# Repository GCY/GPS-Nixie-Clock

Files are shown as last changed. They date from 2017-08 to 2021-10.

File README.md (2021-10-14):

# GPS-Nixie-Clock

This is GPS Nixie clock,include IN12B, IN14, IN16, and IN2 version.</br>

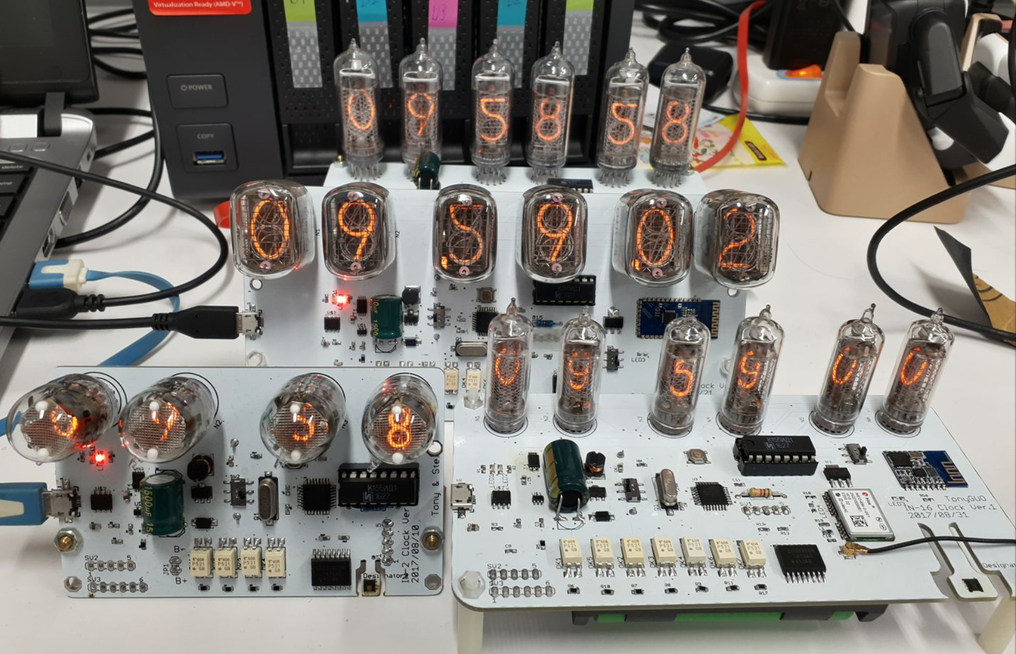
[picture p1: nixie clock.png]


## Firmware
### Parameter

__SERIAL__ : output info to serial port.</br>
DOT : use nixie tube dot.</br>
__GPS__ : time sync with Neo-6M - u-blox chip, this function only for IN14 IN16 version, and time sync separator is GPGGA[7] = {'$','G','P','G','G','A',','};</br>
<pre><code>
#define __SERIAL__ 1
#define DOT 1
#define __GPS__ 1
</code></pre>

gps_update : gps sync period, unit is ms, 300000ms = 5min.</br> 
<pre><code>
const unsigned long gps_update = 300000;
</code></pre>

Type select, IN_14 == IN_16.</br> 
<pre><code>
enum{
  IN_12B = 100,
  IN_14,
  IN_2
};
</code></pre>

<pre><code>
const bool sync_time = false; // sync time with Arduino IDE
const bool temperature_calibration = false; // offset
const bool dew_point = true;  // calculate dew point
</code></pre>
### Command

case '1' : clock mode
</br>
case '2' : temperature mode
</br>
case '3' : humidity mode
</br>
case '4' : flash mode
</br>
case '5' : counter mode
</br>
case '6' : '1' + '2' + '3'
</br>
case 's' | 'S' : set time
</br></br>

## Android time sync tool
Android App modified BlueTerm project. </br>

## PC Software - wxNixieClock
</br>
wxNixieClock is time sync tool for Nixie Clock project.(Only MAC-OS-X)</br>

### Build

g++ -o2 -o wxnixieclock.app wxnixieclock.cpp serialport.cpp connectargsdlg.cpp \`wx-config --cxxflags --libs\` -m64</br>
</br>
</br>

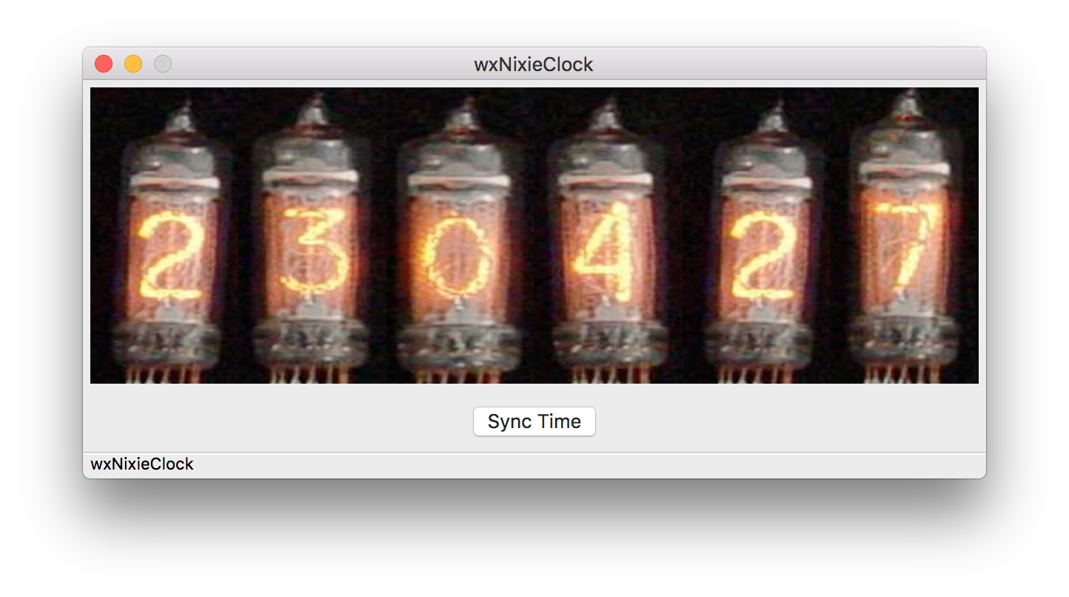
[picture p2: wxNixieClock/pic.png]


</br>
</br>

Audi R8 (https://youtu.be/tJzohsqhTxs)

### Use
</br>
1. Pair BT of MAC and Nixie Clock.</br>
2. Open wxNixieClock to select tools -> Connect Device -> cu.BT device driver</br>
3. Click SyncTime button</br>
4. Done!</br>
</br>

### Dependency

</br>
Install wxWidgets dependency in terminal</br>
</br>
1. user$ /usr/bin/ruby -e "$(curl -fsSL https://raw.githubusercontent.com/Homebrew/install/master/install)" </br>
2. brew install wxwidgets </br>

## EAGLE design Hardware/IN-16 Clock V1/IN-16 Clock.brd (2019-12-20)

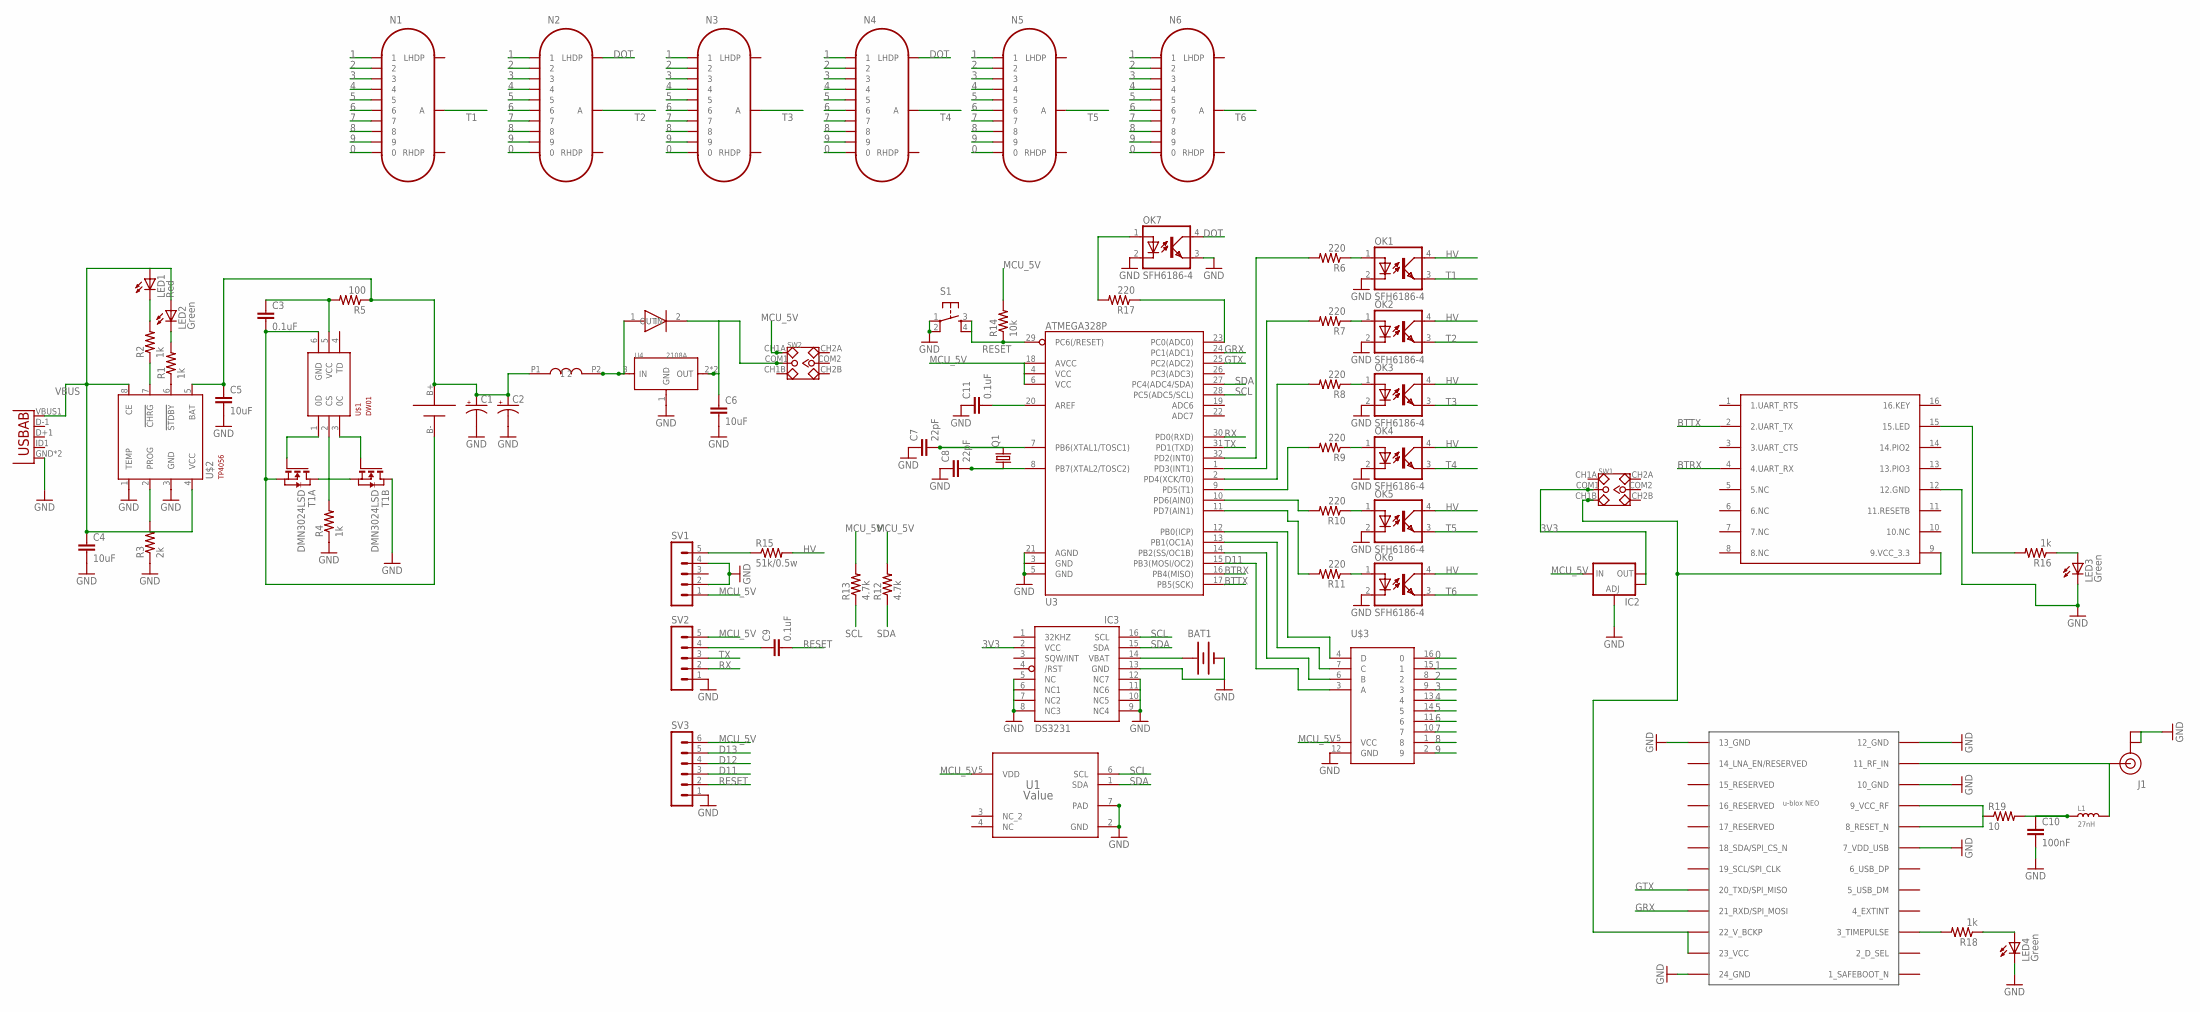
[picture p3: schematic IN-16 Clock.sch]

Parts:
BAT1: BATTERY20PTH; BATTCOM_20MM_PTH
C1, C2: CAP_POLF80; NIPPON_F80
C3, C9, C11: 0.1uF; 0603-CAP
C4, C5, C6: 10uF; 0603-CAP
C7, C8: 22pF; 0603-CAP
C10: 100nF; 0402-CAP
IC2: V_REG_LM1117SOT223; SOT223
IC3: DS3231/SO; SO16W
J1: U.FL
L1: 27nH; L0603
LED1: Red; CHIP-LED0805
LED2, LED3, LED4: Green; CHIP-LED0805
N1, N2, N3, N4, N5, N6: IN-16
OK1, OK2, OK3, OK4, OK5, OK6, OK7: SFH6186-4; SMD4-7
Q1: CRYSTALSM49; SM49
R1, R2, R4, R16, R18: 1k; 0603-RES
R3: 2k; 0603-RES
R5: 100; 0603-RES
R6, R7, R8, R9, R10, R11, R17: 220; 0603-RES
R12, R13: 4.7k; 0603-RES
R14: 10k; 0603-RES
R15: 51k/0.5w; 0207/12
R19: 10; 0603-RES
S1: TAC_SWITCHSMD; TACTILE_SWITCH_SMD
SV1, SV2: MA05-1
SV3: MA06-1
SW1, SW2: SMD-TOGGLE-SWITCH-2CH(2X3P-7X3.5MM); SW6-2.54-SMD-7.0X3.5X1.5MM
T1: DMN3024LSD; TSSOP-8
U1: Value; DMB0006A
U2: USB""; USB-MICRO-SMD
U3: ATMEGA328P; TQFP32-08
U4: 2108A; SOT-89
U$1: DW01; SOT23-6
U$2: TP4056; SOT23-8
U$3: K155ID1; DIL16-KIT
U$5: 22uH; CD54
U$6: SMA-SS34
U$7: 18650SMD
U$8: NEO-M8
U$9: HM-13

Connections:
0: N1.0, N2.0, N3.0, N4.0, N5.0, N6.0, U$3.16 (0)
1: N1.1, N2.1, N3.1, N4.1, N5.1, N6.1, U$3.15 (1)
2: N1.2, N2.2, N3.2, N4.2, N5.2, N6.2, U$3.8 (2)
3: N1.3, N2.3, N3.3, N4.3, N5.3, N6.3, U$3.9 (3)
3V3: IC2.2 (OUT), IC2.4 (OUT), IC3.2 (VCC), SW1.COM1
4: N1.4, N2.4, N3.4, N4.4, N5.4, N6.4, U$3.13 (4)
5: N1.5, N2.5, N3.5, N4.5, N5.5, N6.5, U$3.14 (5)
6: N1.6, N2.6, N3.6, N4.6, N5.6, N6.6, U$3.11 (6)
7: N1.7, N2.7, N3.7, N4.7, N5.7, N6.7, U$3.10 (7)
8: N1.8, N2.8, N3.8, N4.8, N5.8, N6.8, U$3.1 (8)
9: N1.9, N2.9, N3.9, N4.9, N5.9, N6.9, U$3.2 (9)
BTRX: U3.16 (PB4(MISO)), U$9.4 (4.UART_RX)
BTTX: U3.17 (PB5(SCK)), U$9.2 (2.UART_TX)
D11: SV3.3, U3.15 (PB3(MOSI/OC2)), U$3.3 (A)
D12: SV3.4
D13: SV3.5
DOT: N2.LHDP, N4.LHDP, OK7.4 (COL)
GND: BAT1.2 (-), C1.-, C2.-, C4.2, C5.2, C6.2, C7.1, C8.1, C10.2, C11.1, IC2.1 (ADJ), IC3.5 (NC), IC3.6 (NC1), IC3.7 (NC2), IC3.8 (NC3), IC3.9 (NC4), IC3.10 (NC5), IC3.11 (NC6), IC3.12 (NC7), IC3.13 (GND), J1.P$1 (GND), J1.P$2 (GND), LED3.C, LED4.C, OK1.2 (C), OK2.2 (C), OK3.2 (C), OK4.2 (C), OK5.2 (C), OK6.2 (C), OK7.2 (C), OK7.3 (EMIT), R3.1, R4.1, S1.1, S1.2, SV1.2, SV1.4, SV2.1, SV3.1, T1.8 (D), U1.2 (GND), U1.7 (PAD), U2.GND, U2.GND1 (GND), U3.3 (GND), U3.5 (GND), U3.21 (AGND), U4.1 (GND), U$2.1 (TEMP), U$2.3 (GND), U$3.12 (GND), U$8.7 (7_VDD_USB), U$8.10 (10_GND), U$8.12 (12_GND), U$8.13 (13_GND), U$8.24 (24_GND), U$9.12 (12.GND)
GRX: U3.24 (PC1(ADC1)), U$8.21 (21_RXD/SPI_MOSI)
GTX: U3.25 (PC2(ADC2)), U$8.20 (20_TXD/SPI_MISO)
HV: OK1.4 (COL), OK2.4 (COL), OK3.4 (COL), OK4.4 (COL), OK5.4 (COL), OK6.4 (COL), R15.2
MCU_5V: IC2.3 (IN), R12.2, R13.2, R14.2, SV1.1, SV2.5, SV3.6, SW2.CH1A, U1.5 (VDD), U3.4 (VCC), U3.6 (VCC), U3.18 (AVCC), U$3.5 (VCC)
unnamed: LED2.C, R1.2
unnamed: R1.1, U$2.6 (!STDBY)
unnamed: LED1.C, R2.2
unnamed: R2.1, U$2.7 (!CHRG)
unnamed: R3.2, U$2.2 (PROG)
unnamed: U4.3 (IN), U$5.P2 (2), U$6.1 (IN)
unnamed: C6.1, SW2.COM1, U4.2 (OUT), U4.4 (OUT), U$6.2 (OUT)
unnamed: T1.1 (D), T1.6 (S), T1.7 (S)
unnamed: T1.4 (G), U$1.1 (0D)
unnamed: T1.5 (G), U$1.3 (0C)
unnamed: R4.2, U$1.2 (CS)
unnamed: C3.2, T1.2 (S), T1.3 (S), U$1.6 (GND), U$7.B-
unnamed: C3.1, R5.2, U$1.5 (VCC)
unnamed: C1.+, C2.+, C5.1, R5.1, U$2.5 (BAT), U$5.P1 (1), U$7.B+
unnamed: C7.2, Q1.2, U3.7 (PB6(XTAL1/TOSC1))
unnamed: C8.2, Q1.1, U3.8 (PB7(XTAL2/TOSC2))
unnamed: BAT1.1 (+), IC3.14 (VBAT)
unnamed: C11.2, U3.20 (AREF)
unnamed: R15.1, SV1.5
unnamed: R18.2, U$8.3 (3_TIMEPULSE)
unnamed: LED4.A, R18.1
unnamed: OK1.1 (A), R6.1
unnamed: OK2.1 (A), R7.1
unnamed: OK3.1 (A), R8.1
unnamed: OK4.1 (A), R9.1
unnamed: OK5.1 (A), R10.1
unnamed: OK6.1 (A), R11.1
unnamed: R6.2, U3.32 (PD2(INT0))
unnamed: R7.2, U3.1 (PD3(INT1))
unnamed: R8.2, U3.2 (PD4(XCK/T0))
unnamed: R9.2, U3.9 (PD5(T1))
unnamed: R10.2, U3.10 (PD6(AIN0))
unnamed: R11.2, U3.11 (PD7(AIN1))
unnamed: U3.12 (PB0(ICP)), U$3.4 (D)
unnamed: U3.13 (PB1(OC1A)), U$3.7 (C)
unnamed: U3.14 (PB2(SS/OC1B)), U$3.6 (B)
unnamed: R17.1, U3.23 (PC0(ADC0))
unnamed: SW1.CH1B, U$8.22 (22_V_BCKP), U$8.23 (23_VCC), U$9.9 (9.VCC_3.3)
unnamed: OK7.1 (A), R17.2
unnamed: C9.1, SV2.4
unnamed: R16.2, U$9.15 (15.LED)
unnamed: LED3.A, R16.1
unnamed: C10.1, L1.1, R19.2
unnamed: R19.1, U$8.8 (8_RESET_N), U$8.9 (9_VCC_RF)
unnamed: J1.P$3 (SIGNAL), L1.2, U$8.11 (11_RF_IN)
RESET: C9.2, R14.1, S1.3, S1.4, SV3.2, U3.29 (PC6(/RESET))
RX: SV2.2, U3.30 (PD0(RXD))
SCL: IC3.16 (SCL), R13.1, U1.6 (SCL), U3.28 (PC5(ADC5/SCL))
SDA: IC3.15 (SDA), R12.1, U1.1 (SDA), U3.27 (PC4(ADC4/SDA))
T1: N1.A, OK1.3 (EMIT)
T2: N2.A, OK2.3 (EMIT)
T3: N3.A, OK3.3 (EMIT)
T4: N4.A, OK4.3 (EMIT)
T5: N5.A, OK5.3 (EMIT)
T6: N6.A, OK6.3 (EMIT)
TX: SV2.3, U3.31 (PD1(TXD))
VBUS: C4.1, LED1.A, LED2.A, U2.VBUS1 (VBUS), U$2.4 (VCC), U$2.8 (CE)

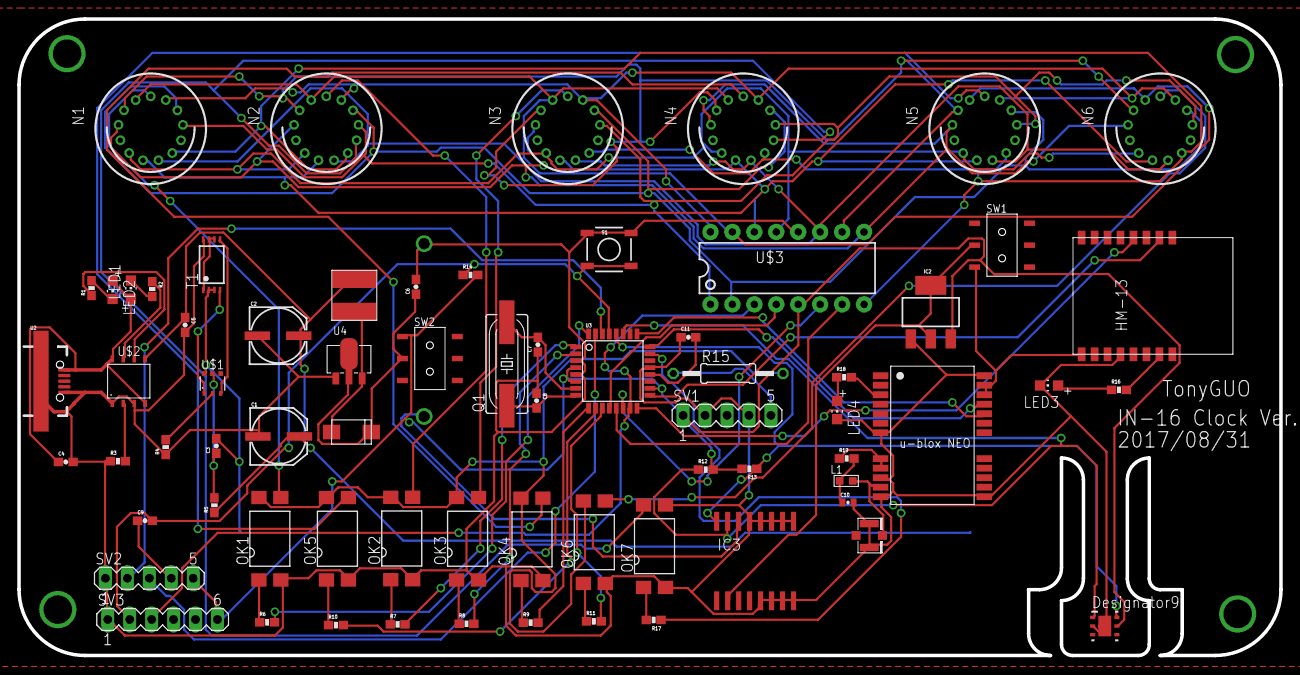
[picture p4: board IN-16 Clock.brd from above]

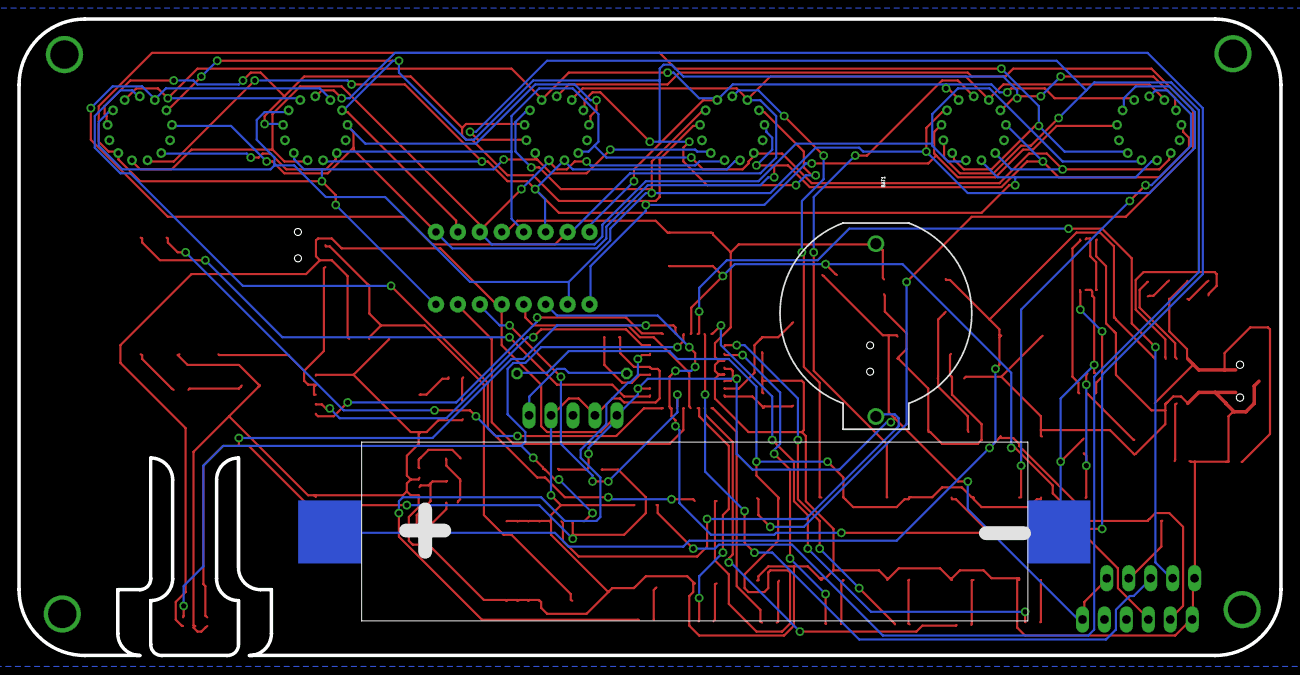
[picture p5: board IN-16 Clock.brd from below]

Board: 2 copper layers, 146.0 x 73.7 mm, 72 parts (2 on the bottom side), 77 nets.

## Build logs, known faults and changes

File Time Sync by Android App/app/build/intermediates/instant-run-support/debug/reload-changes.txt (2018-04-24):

CHANGED,/Users/gcy/Downloads/RoBoHoN connect TPR device/BlueTerm-master/app/build/intermediates/transforms/instantRun/debug/folders/4000/5/enhanced/es/pymasde/blueterm/BlueTerm$3$override.class
CHANGED,/Users/gcy/Downloads/RoBoHoN connect TPR device/BlueTerm-master/app/build/intermediates/transforms/instantRun/debug/folders/4000/5/enhanced/es/pymasde/blueterm/EmulatorView$1$override.class
CHANGED,/Users/gcy/Downloads/RoBoHoN connect TPR device/BlueTerm-master/app/build/intermediates/transforms/instantRun/debug/folders/4000/5/enhanced/es/pymasde/blueterm/BlueTerm$5$override.class
CHANGED,/Users/gcy/Downloads/RoBoHoN connect TPR device/BlueTerm-master/app/build/intermediates/transforms/instantRun/debug/folders/4000/5/enhanced/es/pymasde/blueterm/EmulatorView$2$override.class
CHANGED,/Users/gcy/Downloads/RoBoHoN connect TPR device/BlueTerm-master/app/build/intermediates/transforms/instantRun/debug/folders/4000/5/enhanced/es/pymasde/blueterm/TermKeyListener$override.class
CHANGED,/Users/gcy/Downloads/RoBoHoN connect TPR device/BlueTerm-master/app/build/intermediates/transforms/instantRun/debug/folders/4000/5/enhanced/es/pymasde/blueterm/TermKeyListener$ModifierKey$override.class
CHANGED,/Users/gcy/Downloads/RoBoHoN connect TPR device/BlueTerm-master/app/build/intermediates/transforms/instantRun/debug/folders/4000/5/enhanced/es/pymasde/blueterm/EmulatorView$override.class
CHANGED,/Users/gcy/Downloads/RoBoHoN connect TPR device/BlueTerm-master/app/build/intermediates/transforms/instantRun/debug/folders/4000/5/enhanced/com/android/tools/fd/runtime/AppPatchesLoaderImpl.class
CHANGED,/Users/gcy/Downloads/RoBoHoN connect TPR device/BlueTerm-master/app/build/intermediates/transforms/instantRun/debug/folders/4000/5/enhanced/es/pymasde/blueterm/TerminalEmulator$override.class
CHANGED,/Users/gcy/Downloads/RoBoHoN connect TPR device/BlueTerm-master/app/build/intermediates/transforms/instantRun/debug/folders/4000/5/enhanced/es/pymasde/blueterm/BaseTextRenderer$override.class
CHANGED,/Users/gcy/Downloads/RoBoHoN connect TPR device/BlueTerm-master/app/build/intermediates/transforms/instantRun/debug/folders/4000/5/enhanced/es/pymasde/blueterm/ByteQueue$override.class
CHANGED,/Users/gcy/Downloads/RoBoHoN connect TPR device/BlueTerm-master/app/build/intermediates/transforms/instantRun/debug/folders/4000/5/enhanced/es/pymasde/blueterm/BlueTerm$4$override.class
CHANGED,/Users/gcy/Downloads/RoBoHoN connect TPR device/BlueTerm-master/app/build/intermediates/transforms/instantRun/debug/folders/4000/5/enhanced/es/pymasde/blueterm/PaintRenderer$override.class
CHANGED,/Users/gcy/Downloads/RoBoHoN connect TPR device/BlueTerm-master/app/build/intermediates/transforms/instantRun/debug/folders/4000/5/enhanced/es/pymasde/blueterm/EmulatorView$3$override.class
CHANGED,/Users/gcy/Downloads/RoBoHoN connect TPR device/BlueTerm-master/app/build/intermediates/transforms/instantRun/debug/folders/4000/5/enhanced/es/pymasde/blueterm/BlueTerm$override.class
CHANGED,/Users/gcy/Downloads/RoBoHoN connect TPR device/BlueTerm-master/app/build/intermediates/transforms/instantRun/debug/folders/4000/5/enhanced/es/pymasde/blueterm/TranscriptScreen$override.class

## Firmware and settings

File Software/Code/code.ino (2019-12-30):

#define __SERIAL__ 1
#define DOT 1
#define __GPS__ 1

#ifdef DOT
bool dot = true;
#endif

#include <avr/wdt.h>
#include <Wire.h>
#include <EEPROM.h>

#ifdef __SERIAL__
#include <SoftwareSerial.h>
#endif

#include "RTClib.h"
#include "ClosedCube_HDC1080.h"

#ifdef __SERIAL__
SoftwareSerial serial(13, 12); // RX,TX
#endif

#ifdef __GPS__
#include <TinyGPS.h>

TinyGPS gps;
SoftwareSerial ss(16,15);

static const char GPGGA[7] = {'$','G','P','G','G','A',','};
int gps_sync_gmt_time_index = 0;
char gps_sync_gmt_time[6];

unsigned long gps_time = 0;
unsigned long timeout = 0;
boolean timeout_flag = false;
const unsigned long gps_update = 300000; /*86400000;*/
#endif

enum{
  IN_12B = 100,
  IN_14,
  IN_2
};

const int type = IN_14;

const bool sync_time = false;
const bool temperature_calibration = false;
const bool dew_point = true;

//RTC_DS1307 rtc;
RTC_DS3231 rtc;

ClosedCube_HDC1080 hdc1080;

unsigned long snt = 0;

int tubes[] = {2,3,4,5,6,7};
int K1551[] = {8,9,10,11};

float temperature = 0;
float humidity = 0;

int h = 0;
int m = 0;
int s = 0;  

unsigned long dot_last_time = 0;
unsigned long sn = 0;

unsigned short state = 0; 

const unsigned long s1 = 10000;
const unsigned long s2 = 12000;
const unsigned long s3 = 14000;
unsigned long sr = 0;

static char mode = '6';

float HDC1080DewPoint(float temperature,float humidity)
{
  return (243.12 * (log(humidity/100.0)+ ((17.62*temperature)/(243.12+temperature)))) / (17.62 - (log(humidity/100.0)+ ((17.62*temperature)/(243.12+temperature))));
}

void UpdateHDC1080Temperature()
{
  static int c = 0;
  static float temperature_t = 0;
  static const float ma = 1.0f;
  if(c < ma){
    temperature_t += hdc1080.readTemperature();
    ++c;
  }
  else if(c >= ma){
    temperature = temperature_t / ma;
    
    if(dew_point){
      temperature = HDC1080DewPoint(temperature,humidity);
    }
    
    if(temperature_calibration){
      //temperature -= 4.5f; // Offset
    }
    
    temperature_t = 0;
    c = 0; 
  }
}

void UpdateHDC1080Humidity()
{
  static int c = 0;
  static float humidity_t = 0;
  static const float ma = 1.0f;
  if(c < ma){
    humidity_t += hdc1080.readHumidity();
    ++c;
  }
  else if(c >= ma){
    humidity = humidity_t / ma;
    humidity_t = 0;
    c = 0;
  }
}

void BCD(int val)
{  
  if(val & 0x01){
    digitalWrite(K1551[3],HIGH);
  }
  else{
    digitalWrite(K1551[3],LOW);
  }
  if(val & 0x02){
    digitalWrite(K1551[2],HIGH);
  }
  else{
    digitalWrite(K1551[2],LOW);
  }  
  if(val & 0x04){
    digitalWrite(K1551[1],HIGH);
  }
  else{
    digitalWrite(K1551[1],LOW);
  }    
  if(val & 0x04){
    digitalWrite(K1551[1],HIGH);
  }
  else{
    digitalWrite(K1551[1],LOW);
  }    
  if(val & 0x08){
    digitalWrite(K1551[0],HIGH);
  }
  else{
    digitalWrite(K1551[0],LOW);
  }        
}

void DisplayTemperature()
{
  static const int dt1 = 200;   
  static const int dt2 = 800;   
   
  digitalWrite(tubes[5],LOW);
  delayMicroseconds(dt1);
  BCD(((int)temperature)/10);
  digitalWrite(tubes[2],HIGH);
  delayMicroseconds(dt2);
  digitalWrite(tubes[2],LOW);
  delayMicroseconds(dt1);
  BCD(((int)temperature)%10);
  digitalWrite(tubes[3],HIGH);
  delayMicroseconds(dt2);
  digitalWrite(tubes[3],LOW);
  delayMicroseconds(dt1);
  if(!(type == IN_2)){
    BCD( (int)( (temperature - ((int)temperature)) * 100) / 10);
    #ifdef DOT
    digitalWrite(A0,HIGH);
    #endif
    digitalWrite(tubes[4],HIGH);
    delayMicroseconds(dt2);
    #ifdef DOT
    digitalWrite(A0,LOW);
    #endif
    digitalWrite(tubes[4],LOW);
    delayMicroseconds(dt1);
    BCD( (int)( (temperature - ((int)temperature)) * 100) % 10);
    digitalWrite(tubes[5],HIGH);
    delayMicroseconds(dt2);   
    digitalWrite(tubes[5],LOW);  
  }
}

void DisplayHumidity()
{
  static const int dt1 = 200;    
  static const int dt2 = 800;
  digitalWrite(tubes[5],LOW);
  delayMicroseconds(dt1);
  BCD(((int)humidity)/10);
  digitalWrite(tubes[2],HIGH);
  delayMicroseconds(dt2);
  digitalWrite(tubes[2],LOW);
  delayMicroseconds(dt1);
  BCD(((int)humidity)%10);
  digitalWrite(tubes[3],HIGH);
  delayMicroseconds(dt2);
  digitalWrite(tubes[3],LOW);
  delayMicroseconds(dt1);
  if(!(type == IN_2)){
    BCD( (int)( (humidity - ((int)humidity)) * 100) / 10);
    #ifdef DOT
    digitalWrite(A0,HIGH);
    #endif
    digitalWrite(tubes[4],HIGH);
    delayMicroseconds(dt2);
    #ifdef DOT
    digitalWrite(A0,LOW);
    #endif
    digitalWrite(tubes[4],LOW);
    delayMicroseconds(dt1);
    BCD( (int)( (humidity - ((int)humidity)) * 100) % 10);
    digitalWrite(tubes[5],HIGH);
    delayMicroseconds(dt2);     
    digitalWrite(tubes[5],LOW);
  }
}

void DisplayTime()
{
  
  DateTime now = rtc.now();
  h = now.hour();
  m = now.minute();
  s = now.second();  

  static const int dt1 = 100;  
  static const int dt2 = 400;
  
  digitalWrite(tubes[5],LOW);
  delayMicroseconds(dt1);
  BCD(h/10);
  digitalWrite(tubes[0],HIGH);
  delayMicroseconds(dt2);
  digitalWrite(tubes[0],LOW);
  delayMicroseconds(dt1);
  BCD(h%10);  
  digitalWrite(tubes[1],HIGH);
  delayMicroseconds(dt2);
  digitalWrite(tubes[1],LOW);
  delayMicroseconds(dt1);
  BCD(m/10);
  #ifdef DOT
  if(dot){
    digitalWrite(A0,HIGH);
  }  
  #endif
  digitalWrite(tubes[2],HIGH);
  delayMicroseconds(dt2);
  #ifdef DOT
  if(dot){
    digitalWrite(A0,LOW);
  }  
  #endif
  digitalWrite(tubes[2],LOW);
  delayMicroseconds(dt1);
  BCD(m%10);
  digitalWrite(tubes[3],HIGH);
  delayMicroseconds(dt2);
  digitalWrite(tubes[3],LOW);
  delayMicroseconds(dt1);
  if(!(type == IN_2)){
    BCD(s/10);
    #ifdef DOT
    if(dot){
      digitalWrite(A0,HIGH);
    }  
    #endif
    digitalWrite(tubes[4],HIGH);
    delayMicroseconds(dt2);
    #ifdef DOT
    if(dot){
      digitalWrite(A0,LOW);
    }  
    #endif
    digitalWrite(tubes[4],LOW);
    delayMicroseconds(dt1);
    BCD(s%10);
    digitalWrite(tubes[5],HIGH);
    delayMicroseconds(dt2);   
    digitalWrite(tubes[5],LOW);
  }
}

void DisplayRandom()
{
  static const int dt1 = 500;  
  static const int dt2 = 10000;
  
  digitalWrite(tubes[5],LOW);
  delayMicroseconds(dt1);
  BCD(random(0,9));
  digitalWrite(tubes[0],HIGH);
  delayMicroseconds(dt2);
  digitalWrite(tubes[0],LOW);
  delayMicroseconds(dt1);
  BCD(random(0,9));
  digitalWrite(tubes[1],HIGH);
  delayMicroseconds(dt2);
  digitalWrite(tubes[1],LOW);
  delayMicroseconds(dt1);
  BCD(random(0,9));
  digitalWrite(tubes[2],HIGH);
  delayMicroseconds(dt2);
  digitalWrite(tubes[2],LOW);
  delayMicroseconds(dt1);
  BCD(random(0,9));
  digitalWrite(tubes[3],HIGH);
  delayMicroseconds(dt2);
  digitalWrite(tubes[3],LOW);
  delayMicroseconds(dt1);
  BCD(random(0,9));
  digitalWrite(tubes[4],HIGH);
  delayMicroseconds(dt2);
  digitalWrite(tubes[4],LOW);
  delayMicroseconds(dt1);
  BCD(random(0,9));
  digitalWrite(tubes[5],HIGH);
  delayMicroseconds(dt2);   
  digitalWrite(tubes[5],LOW);  
}

void DisplaySN()
{
  static const int dt1 = 200;  
  static const int dt2 = 800;
  
  digitalWrite(tubes[5],LOW);
  delayMicroseconds(dt1);
  BCD(sn);
  digitalWrite(tubes[0],HIGH);
  delayMicroseconds(dt2);
  digitalWrite(tubes[0],LOW);
  delayMicroseconds(dt1);
  BCD(sn);
  digitalWrite(tubes[1],HIGH);
  delayMicroseconds(dt2);
  digitalWrite(tubes[1],LOW);
  delayMicroseconds(dt1);
  BCD(sn);
  digitalWrite(tubes[2],HIGH);
  delayMicroseconds(dt2);
  digitalWrite(tubes[2],LOW);
  delayMicroseconds(dt1);
  BCD(sn);
  digitalWrite(tubes[3],HIGH);
  delayMicroseconds(dt2);
  digitalWrite(tubes[3],LOW);
  delayMicroseconds(dt1);
  BCD(sn);
  digitalWrite(tubes[4],HIGH);
  delayMicroseconds(dt2);
  digitalWrite(tubes[4],LOW);
  delayMicroseconds(dt1);
  BCD(sn);
  digitalWrite(tubes[5],HIGH);
  delayMicroseconds(dt2);   
  digitalWrite(tubes[5],LOW);
}

void setup() {

  wdt_enable (WDTO_1S);

  snt = millis();
  sr = millis();

  #ifdef __SERIAL__
  Serial.begin(9600);
  if(type == IN_12B){
    serial.begin(9600);
  }
  else if(type == IN_14){
    serial.begin(115200);
    #ifdef __GPS__
    //ss.begin(9600);
    gps_time = millis();
    #endif
  }
  #endif  
  
  Wire.begin();
  Wire.setClock(3400000);
  
  rtc.begin();
  if(sync_time){
    rtc.adjust(DateTime(F(__DATE__), F(__TIME__)));
  }
  
  hdc1080.begin(0x40);

  randomSeed(analogRead(A3));

  pinMode(A0,OUTPUT);
  
  for(int i = 0;i < (sizeof(tubes)/sizeof(tubes[0]));++i){
    pinMode(tubes[i],OUTPUT);
    digitalWrite(tubes[i],LOW);
  }
  for(int i = 0;i < (sizeof(K1551)/sizeof(K1551[0]));++i){
    pinMode(K1551[i],OUTPUT);
  } 

  UpdateHDC1080Temperature();
  UpdateHDC1080Humidity();

}

const static int set_time_length = 15;
char set_time[set_time_length];
char set_time_index = 0;

void loop() {
  #ifdef __SERIAL__

  while(Serial.available()) {
    char temp = Serial.read();
    
    if(temp >= '0' && temp <= '9'){
      mode = temp;
    }

    if(set_time_index < set_time_length){
      set_time[set_time_index++] = temp;
    }
    
    if(set_time_index == set_time_length){
      set_time_index = 0;
      if(set_time[0] == 's' || set_time[0] == 'S'){
        
        boolean set_time_flag = true;
        
        for(int i = 1;i < set_time_length;++i){
          if(set_time[i] >= '0' && set_time[i] <= '9'){
          }
          else{
            set_time_flag = false;
          }
        }

        if(set_time_flag){
          char year_char[5];
          char month_char[3];
          char day_char[3];
          char hour_char[3];
          char minute_char[3];
          char second_char[3];

          year_char[0] = set_time[1];
          year_char[1] = set_time[2];
          year_char[2] = set_time[3];
          year_char[3] = set_time[4];

          month_char[0] = set_time[5];
          month_char[1] = set_time[6];

          day_char[0] = set_time[7];
          day_char[1] = set_time[8];

          hour_char[0] = set_time[9];
          hour_char[1] = set_time[10];          

          minute_char[0] = set_time[11];
          minute_char[1] = set_time[12];   

          second_char[0] = set_time[13];
          second_char[1] = set_time[14];   

          int set_year = atoi(year_char);
          int set_month = atoi(month_char);
          int set_day = atoi(day_char);
          int set_hour = atoi(hour_char);
          int set_minute = atoi(minute_char);
          int set_second = atoi(second_char);    

          if(set_year < 1970){
            set_time_flag = false;
          }
          if(set_month < 1 || set_month > 12){
            set_time_flag = false;
          }
          if(set_day < 1 || set_day > 31){
            set_time_flag = false;
          }
          if(set_hour < 0 || set_hour > 23){
            set_time_flag = false;
          }    
          if(set_minute < 0 || set_minute > 59){
            set_time_flag = false;
          }
          if(set_second < 0 || set_second > 59){
            set_time_flag = false;
          }        

          if(set_time_flag){
/*            
            Serial.println("Set Time!");
            Serial.println(set_year);
            Serial.println(set_month);
            Serial.println(set_day);
            Serial.println(set_hour);
            Serial.println(set_minute);
            Serial.println(set_second);
*/
            DateTime dt(set_year,set_month,set_day,set_hour,set_minute,set_second);
            rtc.adjust(dt);
/*
            DateTime now = rtc.now();
            Serial.println(now.year());
            Serial.println(now.month());
            Serial.println(now.day());
            Serial.println(now.hour());
            Serial.println(now.minute());
            Serial.println(now.second());            
*/
            mode = '6';
          }
          
        }
        
      }
    }
    
    Serial.write(mode);           
  }  

  while(serial.available()) {
    char temp = serial.read();
    
    if(temp >= '0' && temp <= '9'){
      mode = temp;
    }

    if(set_time_index < set_time_length){
      set_time[set_time_index++] = temp;
    }
    
    if(set_time_index == set_time_length){
      set_time_index = 0;
      if(set_time[0] == 's' || set_time[0] == 'S'){
        
        boolean set_time_flag = true;
        
        for(int i = 1;i < set_time_length;++i){
          if(set_time[i] >= '0' && set_time[i] <= '9'){
          }
          else{
            set_time_flag = false;
          }
        }

        if(set_time_flag){
          char year_char[5];
          char month_char[3];
          char day_char[3];
          char hour_char[3];
          char minute_char[3];
          char second_char[3];

          year_char[0] = set_time[1];
          year_char[1] = set_time[2];
          year_char[2] = set_time[3];
          year_char[3] = set_time[4];

          month_char[0] = set_time[5];
          month_char[1] = set_time[6];

          day_char[0] = set_time[7];
          day_char[1] = set_time[8];

          hour_char[0] = set_time[9];
          hour_char[1] = set_time[10];          

          minute_char[0] = set_time[11];
          minute_char[1] = set_time[12];   

          second_char[0] = set_time[13];
          second_char[1] = set_time[14];   

          int set_year = atoi(year_char);
          int set_month = atoi(month_char);
          int set_day = atoi(day_char);
          int set_hour = atoi(hour_char);
          int set_minute = atoi(minute_char);
          int set_second = atoi(second_char);    

          if(set_year < 1970){
            set_time_flag = false;
          }
          if(set_month < 1 || set_month > 12){
            set_time_flag = false;
          }
          if(set_day < 1 || set_day > 31){
            set_time_flag = false;
          }
          if(set_hour < 0 || set_hour > 23){
            set_time_flag = false;
          }    
          if(set_minute < 0 || set_minute > 59){
            set_time_flag = false;
          }
          if(set_second < 0 || set_second > 59){
            set_time_flag = false;
          }        

          if(set_time_flag){
/*            
            Serial.println("Set Time!");
            Serial.println(set_year);
            Serial.println(set_month);
            Serial.println(set_day);
            Serial.println(set_hour);
            Serial.println(set_minute);
            Serial.println(set_second);
*/
            DateTime dt(set_year,set_month,set_day,set_hour,set_minute,set_second);
            rtc.adjust(dt);
/*
            DateTime now = rtc.now();
            Serial.println(now.year());
            Serial.println(now.month());
            Serial.println(now.day());
            Serial.println(now.hour());
            Serial.println(now.minute());
            Serial.println(now.second());            
*/
            mode = '6';
          }
          
        }
        
      }
    }
    
    serial.write(mode);           
  }  
  #endif

  #ifdef __GPS__
  
  if((millis() - gps_time) > gps_update){
    if(!timeout_flag){
      timeout = millis();
      timeout_flag = true;
    }

    ss.begin(9600);
    while(ss.available()){
      char c = ss.read();

      if(c == GPGGA[gps_sync_gmt_time_index]){
        ++gps_sync_gmt_time_index;
      }
      else if(gps_sync_gmt_time_index < 6){
        gps_sync_gmt_time_index = 0;
      }

      if(gps_sync_gmt_time_index > 6 && gps_sync_gmt_time_index < 14){
        if((gps_sync_gmt_time_index - 8) > -1){
          gps_sync_gmt_time[gps_sync_gmt_time_index - 8] = c;
        }
        ++gps_sync_gmt_time_index;
      }

      if(gps_sync_gmt_time_index >= 14){
        /*
        for(int i = 0;i < 6;++i){
          Serial.print(gps_sync_gmt_time[i]);
        }
        Serial.println();
        */
        
        char hour_char[3];
        char minute_char[3];
        char second_char[3];

        hour_char[0] = gps_sync_gmt_time[0];
        hour_char[1] = gps_sync_gmt_time[1];          

        minute_char[0] = gps_sync_gmt_time[2];
        minute_char[1] = gps_sync_gmt_time[3];   

        second_char[0] = gps_sync_gmt_time[4];
        second_char[1] = gps_sync_gmt_time[5];      

        int set_hour = atoi(hour_char);
        int set_minute = atoi(minute_char);
        int set_second = atoi(second_char);    

        boolean set_time_flag = true;

        for(int i = 0;i < 6;++i){
          if((gps_sync_gmt_time[i] < '0') || (gps_sync_gmt_time[i] > '9')){
            set_time_flag = false;
          }
        }
        
        if(set_hour < 0 || set_hour > 23){
          set_time_flag = false;
        }    
        if(set_minute < 0 || set_minute > 59){
          set_time_flag = false;
        }
        if(set_second < 0 || set_second > 59){
          set_time_flag = false;
        }     

        if(set_time_flag){
          DateTime now = rtc.now();
          DateTime dt(now.year(),now.month(),now.day(),set_hour,set_minute,set_second);
          rtc.adjust(dt + TimeSpan(0,8,0,0));          
        }    
        /*
        DateTime now = rtc.now();
        
        Serial.print(now.year(), DEC);
        Serial.print('/');
        Serial.print(now.month(), DEC);
        Serial.print('/');
        Serial.print(now.day(), DEC);
        Serial.print(" ");
        Serial.print(now.hour(), DEC);
        Serial.print(':');
        Serial.print(now.minute(), DEC);
        Serial.print(':');
        Serial.print(now.second(), DEC);
        Serial.println();    
        */                     

        /*
        for(int i = 0;i < 6;++i){
          gps_sync_gmt_time[i] = 0;
        }        
        */
        
        gps_sync_gmt_time_index = 0;
        timeout_flag = false;
        for(int i = 0;i < sizeof(gps_sync_gmt_time)/sizeof(char);++i){
          gps_sync_gmt_time[i] = 0;
        }
      }
    }

    if((millis() - timeout) > 10000){
      gps_sync_gmt_time_index = 0;
      timeout_flag = false;
    }

    if(!timeout_flag){
      gps_time = millis();
      ss.end();
    }
  }
  #endif

  if(mode == '1'){
    DisplayTime();
  }
  else if(mode == '2'){
    UpdateHDC1080Temperature();
    DisplayTemperature();
  }  
  else if(mode == '3'){
    UpdateHDC1080Humidity();
    DisplayHumidity();
  }  
  else if(mode == '4'){
    DisplayRandom();
  }  
  else if(mode == '5'){
    if((millis() - snt) > 1000){
      snt = millis();
      ++sn;
      if(sn > 9){
        sn = 0;
      }
    }
    DisplaySN();
  }    
  else if(mode == '6'){
    unsigned long srt = millis() - sr;
    if(srt < s1){
      if(state != 0){
        state = 0;
      }
      DisplayTime();
    }
    else if(srt > s1 && srt < s2){
      if(state != 1){
        UpdateHDC1080Temperature();
        state = 1;
      }
      DisplayTemperature();     
    }
    else if(srt > s2 && srt < s3){
      if(state != 2){
        UpdateHDC1080Humidity();
        state = 2;
      }
      DisplayHumidity();      
    }

    if(srt > s3){
      sr = millis();
    }
  }
  else if(mode == '7'){
  }

  #ifdef DOT
  if((millis() - dot_last_time) > 1000){
    dot ^= true;
    dot_last_time = millis();
  }
  #endif

  wdt_reset();

}

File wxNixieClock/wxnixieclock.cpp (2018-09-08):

#include "wxnixieclock.h"

IMPLEMENT_APP(App)
DECLARE_APP(App)

bool App::OnInit()
{
   wxFrame *frame = new Frame(wxT("wxNixieClock"));

   frame->Show(true);

   return true;
}

BEGIN_EVENT_TABLE(Frame,wxFrame)
   EVT_MENU(ID_EXIT,Frame::OnExit)
   EVT_TIMER(ID_TIMER,Frame::OnTimer)
   EVT_BUTTON(ID_SYNC_TIME,Frame::OnSyncTime)
   EVT_MENU(ID_TIME_MODE,Frame::OnTimeMode)
   EVT_MENU(ID_TEMPERATURE_MODE,Frame::OnTemperatureMode)
   EVT_MENU(ID_HUMIDITY_MODE,Frame::OnHumidityMode)
   EVT_MENU(ID_RANDOM_MODE,Frame::OnRandomMode)
   EVT_MENU(ID_COUNTER_MODE,Frame::OnCounterMode)
   EVT_MENU(ID_POLLING_MODE,Frame::OnPollingMode)
   EVT_MENU(ID_CONNECT_DEVICE,Frame::OnConnectDevice)
   EVT_MENU(ID_RELEASE_DEVICE,Frame::OnReleaseDevice)
END_EVENT_TABLE()

Frame::Frame(const wxString &title):wxFrame(NULL,wxID_ANY,title,wxDefaultPosition,wxDefaultSize,wxMINIMIZE_BOX | wxCLOSE_BOX | wxCAPTION),timer(this,ID_TIMER)
{

   wxInitAllImageHandlers();
   wxImage::AddHandler(new wxPNGHandler());
   CreateUI();
   timer.Start(30);

}

void Frame::CreateUI()
{
   wxMenu *file = new wxMenu;
   file->Append(ID_EXIT,wxT("E&xit\tAlt-e"),wxT("Exit"));
   wxMenu *tools = new wxMenu;
   tools->Append(ID_CONNECT_DEVICE,wxT("C&onnect Device\tAlt-c"),wxT("Connect Device"));
   tools->Append(ID_RELEASE_DEVICE,wxT("R&elease Device\tAlt-r"),wxT("Release Device"));
   wxMenu *mode = new wxMenu;
   mode->Append(ID_TIME_MODE,wxT("Time"),wxT("Time"));
   mode->Append(ID_TEMPERATURE_MODE,wxT("Temperature"),wxT("Temperature"));
   mode->Append(ID_HUMIDITY_MODE,wxT("Humidity"),wxT("Humidity"));
   mode->Append(ID_RANDOM_MODE,wxT("Random"),wxT("Random"));
   mode->Append(ID_COUNTER_MODE,wxT("Counter"),wxT("Counter"));
   mode->Append(ID_POLLING_MODE,wxT("Polling"),wxT("Polling"));

   wxMenuBar *bar = new wxMenuBar;
   bar->Append(file,wxT("File"));
   bar->Append(tools,wxT("Tools"));
   bar->Append(mode,wxT("Mode"));
   SetMenuBar(bar);

   wxBoxSizer *top = new wxBoxSizer(wxVERTICAL);
   this->SetSizer(top);

   wxBoxSizer *screen_box = new wxBoxSizer(wxHORIZONTAL);
   top->Add(screen_box,0,wxALIGN_CENTER_HORIZONTAL | wxALL,5);

   for(size_t i = 0;i < TUBE_NUM;++i){
      tubes[i] = new wxPanel(this,wxID_ANY,wxDefaultPosition,wxSize(100,200));
      screen_box->Add(tubes[i],0,wxALIGN_CENTER_HORIZONTAL | wxALIGN_CENTER_VERTICAL,5);
   }

   wxBoxSizer *button_box = new wxBoxSizer(wxHORIZONTAL);
   top->Add(button_box,0,wxALIGN_CENTER_HORIZONTAL | wxALL,5);

   sync_button = new wxButton(this,ID_SYNC_TIME,wxT("&Sync Time"),wxDefaultPosition,wxDefaultSize);
   button_box->Add(sync_button,0,wxALIGN_CENTER_VERTICAL | wxALL,5);   

   CreateStatusBar(2);
   SetStatusText(wxT("wxNixieClock"));

   top->Fit(this);
   top->SetSizeHints(this);
   
}

void Frame::OnConnectDevice(wxCommandEvent &event)
{
    ConnectArgsDialog dlg(this,wxID_ANY,wxT("Connect"),wxDefaultPosition,wxDefaultSize,wxDEFAULT_DIALOG_STYLE);

    if(dlg.ShowModal() == wxID_OK){
       serial.Open(dlg.GetDevicePath().mb_str());
       serial.SetBaudRate(wxAtoi(dlg.GetBaudRate()));
       serial.SetParity(8,1,'N');

    }
}

void Frame::OnTimer(wxTimerEvent &event)
{
   wxDateTime time = wxDateTime::Now();
   unsigned digital[TUBE_NUM];
   digital[0] = time.GetHour() / 10;
   digital[1] = time.GetHour() % 10;
   digital[2] = time.GetMinute() / 10;
   digital[3] = time.GetMinute() % 10;
   digital[4] = time.GetSecond() / 10;
   digital[5] = time.GetSecond() % 10;   
   for(size_t i = 0;i < TUBE_NUM;++i){
      wxClientDC dc(tubes[i]);
      wxString str;
      wxStandardPaths& sp = wxStandardPaths::Get();
      str.Printf("%s/in16/%d.png",sp.GetResourcesDir(),digital[i]);
      wxImage *image = new wxImage(str,wxBITMAP_TYPE_PNG);
      wxBitmap *bitmap = new wxBitmap(*image);      
      int x,y,width,height;
      dc.GetClippingBox(&x,&y,&width,&height);
      //wxLogDebug(wxT("%s"),wxNow());
      bitmap->SetWidth(width);
      bitmap->SetHeight(height);
      dc.DrawBitmap(*bitmap,x,y);

      delete bitmap;
      delete image;
   }   
}

void Frame::OnReleaseDevice(wxCommandEvent &event)
{
   serial.Close();   
}

void Frame::OnSyncTime(wxCommandEvent &event)
{
   
   wxDateTime time = wxDateTime::Now();
   unsigned digital[TUBE_NUM];
   digital[0] = time.GetHour() / 10;
   digital[1] = time.GetHour() % 10;
   digital[2] = time.GetMinute() / 10;
   digital[3] = time.GetMinute() % 10;
   digital[4] = time.GetSecond() / 10;
   digital[5] = time.GetSecond() % 10;    
   unsigned month[2];
   month[0] = (time.GetMonth()+1) / 10;
   month[1] = (time.GetMonth()+1) % 10;
   unsigned day[2];
   day[0] = time.GetDay() / 10;
   day[1] = time.GetDay() % 10;
   
   wxString str;
   str.Printf("s%d%d%d%d%d%d%d%d%d%d%d",time.GetYear(),month[0],month[1],day[0],day[1],digital[0],digital[1],digital[2],digital[3],digital[4],digital[5]);
   unsigned char data[255] = {""};
   int size = str.length();
   strcpy((char*)data,str.c_str());
   serial.Write(data,size);
}

void Frame::OnTimeMode(wxCommandEvent &event)
{
   serial.Write((unsigned char*)"1",1);   
}

void Frame::OnTemperatureMode(wxCommandEvent &event)
{
   serial.Write((unsigned char*)"2",1);   
}

void Frame::OnHumidityMode(wxCommandEvent &event)
{
   serial.Write((unsigned char*)"3",1);   
}

void Frame::OnRandomMode(wxCommandEvent &event)
{
   serial.Write((unsigned char*)"4",1);   
}

void Frame::OnCounterMode(wxCommandEvent &event)
{
   serial.Write((unsigned char*)"5",1);   
}

void Frame::OnPollingMode(wxCommandEvent &event)
{
   serial.Write((unsigned char*)"6",1);   
}

void Frame::OnExit(wxCommandEvent &event)
{
   Close();
}

Frame::~Frame()
{
   for(size_t i = 0;i < TUBE_NUM;++i){
      delete tubes[i];
   }
   
}

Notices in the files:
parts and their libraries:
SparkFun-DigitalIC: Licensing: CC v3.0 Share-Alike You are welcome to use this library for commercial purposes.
